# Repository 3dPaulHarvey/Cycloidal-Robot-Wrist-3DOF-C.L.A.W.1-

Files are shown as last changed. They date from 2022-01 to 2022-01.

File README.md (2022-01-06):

# Cycloidal-Robot-Wrist-3DOF-C.L.A.W.1-
Robot wrist with Cycloidal Gearboxes

Hello, this is one half of a Robot Arm. It is a 3 Degree of Freedom ROBOT WRIST. It is composed of 3 on-axis CYCLOIDAL gearboxes, with gt timing belts and pulleys driving them. This is a continuous motion wrist in all 3 axis.

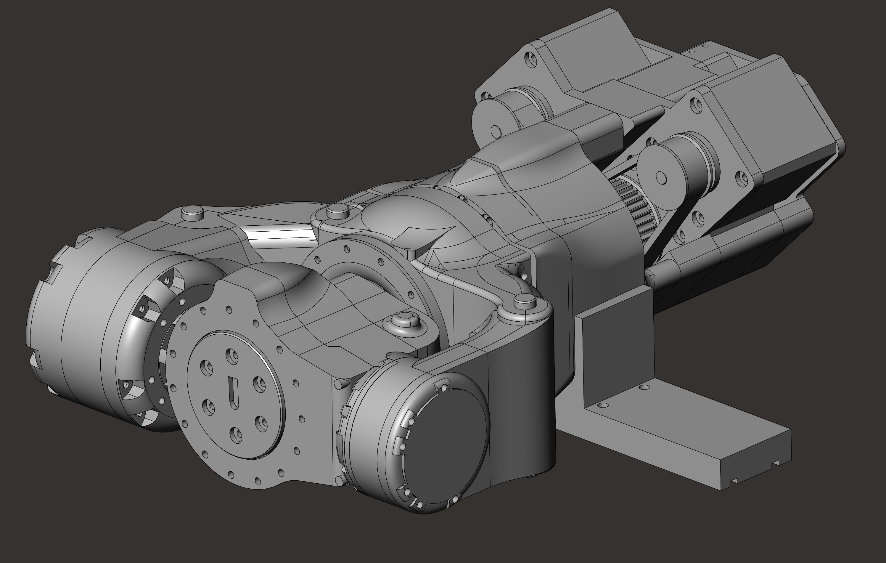
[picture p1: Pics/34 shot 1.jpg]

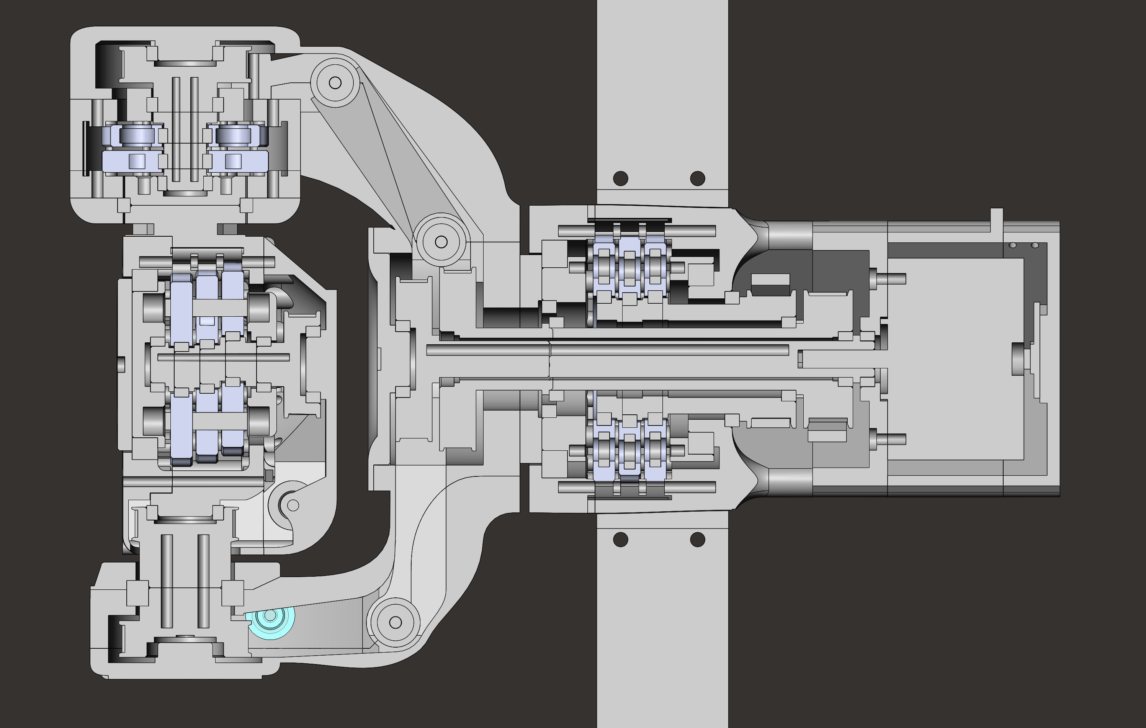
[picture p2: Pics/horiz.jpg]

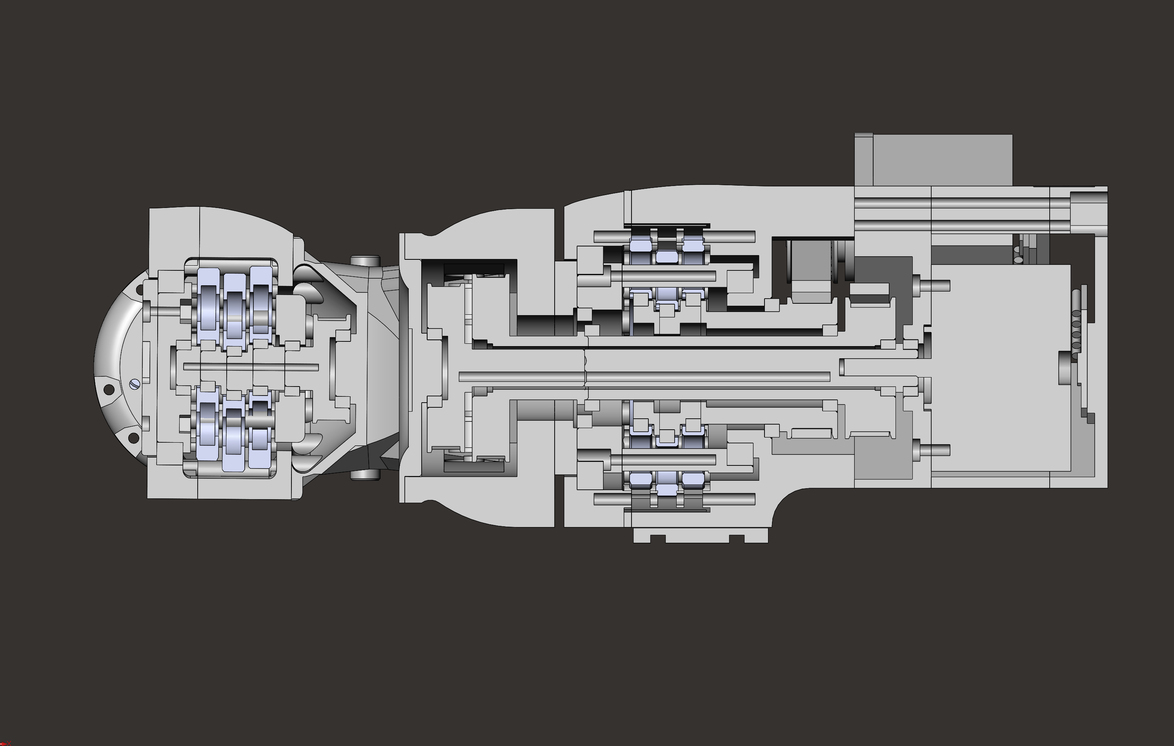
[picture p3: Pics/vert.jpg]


printed on prusa mk3 with overture petg
bom
lots of 3x5x5 sleeve bearings, 3mm bars, 4-40 screws, and other bearings

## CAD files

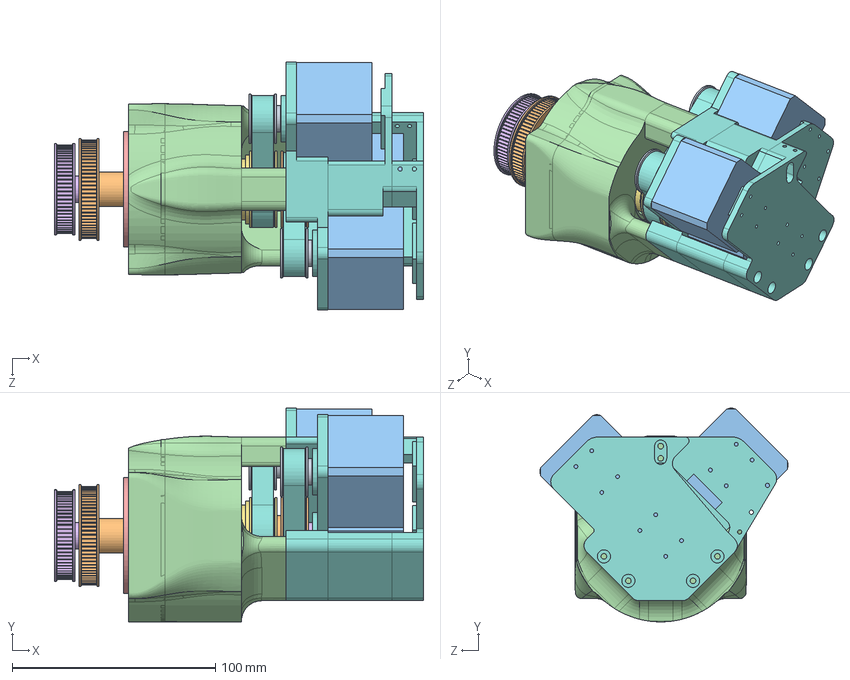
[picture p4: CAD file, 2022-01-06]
SolidWorks/ASSEM-F- 3DOF3 WRIST J4.SLDASM
181.6 x 105.2 x 122.3 mm
3D3- LEFT DRIVE PULLEY x 2
3D3- OUTER SHAFT
STEPPER 42 MM AZN2 x 3
3D3- J4- OUTER HOUSING
3D3- J4- OUTPUT CARRIAGE
3D3- INNER SHAFT
3D3- J4 ECCENTRIC SHAFT
3D3- MOTOR ATTACH2
Cycloidal Lobes 19-1, 70, 5, 1.5- B x 3
3D3-F-J4- 3MM PIN 1 x 20
BEARING- 3x5x5 x 20
3D3-F-J4- DUMMY PINS
3D3-F-J4- OUTPUT ROD
BEARING- 6x10x3 x 3

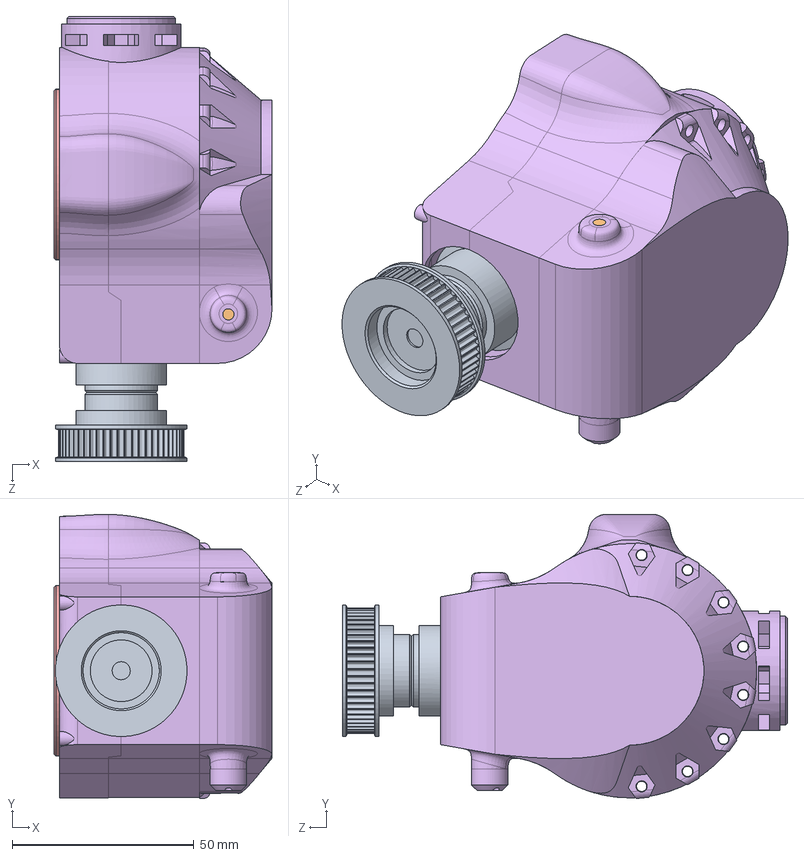
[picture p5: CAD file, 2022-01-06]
SolidWorks/ASSEM-F-J6- 3DOF3 WRIST.SLDASM
60.0 x 78.2 x 122.5 mm
3D3- J6-3- SIDE PULLEY
3D3- J6-3- 3MM BAR
3D3- J6-3- CORNER PULLEY x 2
3D3- J6-3- ECCENTRIC SHAFT
3D3- J6-3- INNER CARRIAGE
3D3- J6-3- OUTER HOUSING
3D3-F-J6- Cycloidal A 56 5 1.5 14-1 x 3
BEARING- 7x13x4 x 3
3D3- J6-3- 3MM PIN x 15
BEARING- 3x5x5 x 15
3D3-F-J6- DUMMY PINS

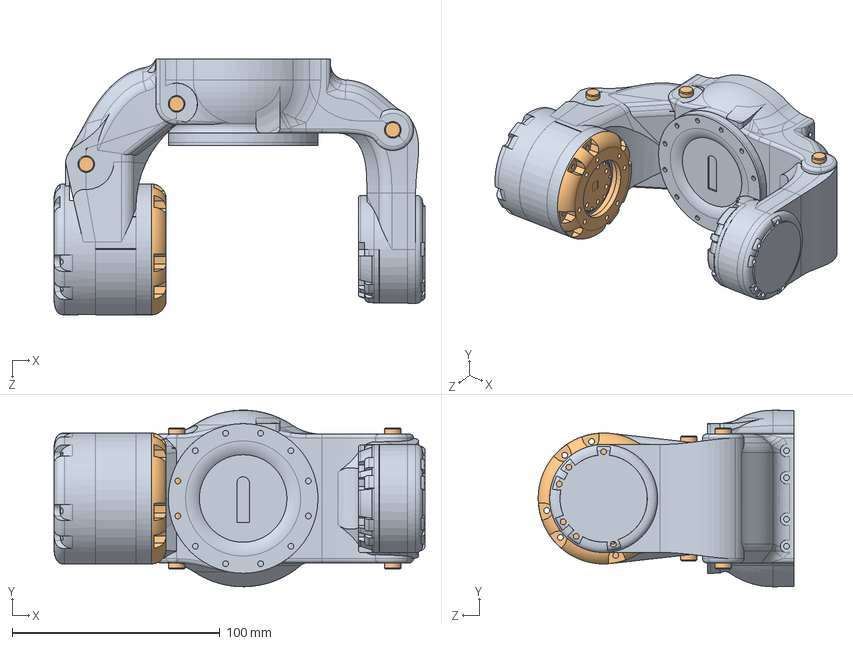
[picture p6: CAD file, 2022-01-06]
SolidWorks/ASSEM-F-J5- 3DOF3 WRIST.SLDASM
178.5 x 85.0 x 123.0 mm
3D3- J5-2- OUTER HOUSING
3D3- J5-2- MID WRIST FRAME
3D3- J6-3- CORNER PULLEY x 6
3D3-F-J5- 3MM CORNER BAR A
3D3-F-J5- 3MM CORNER BAR C
3D3-F-J5- 3MM CORNER BAR B
3D3-J5-2- CYCLOIDAL 11-1rat 48dia 5dia 1.5ecc A x 2
3D3- J5-2- ECCENTRIC SHAFT
3D3- J5-2- INNER CARRIAGE
BEARING- 5x10x4 x 2
3D3-F-J5- 3MM PINS x 12
BEARING- 3x5x5 x 12

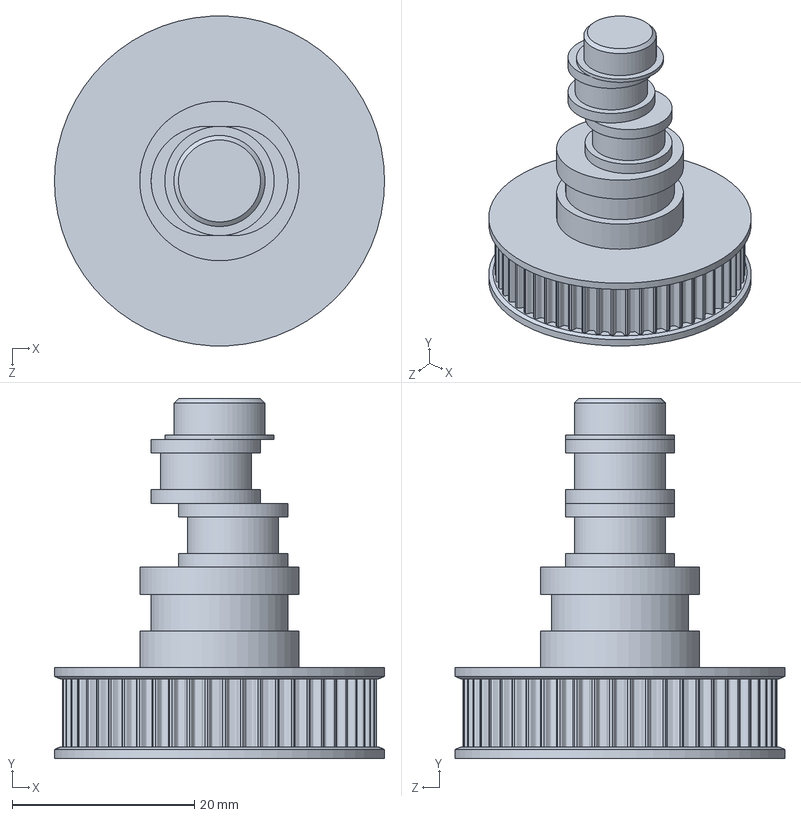
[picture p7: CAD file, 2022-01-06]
SolidWorks/3D3- J5-2- ECCENTRIC SHAFT.SLDPRT
36.2 x 39.5 x 36.2 mm

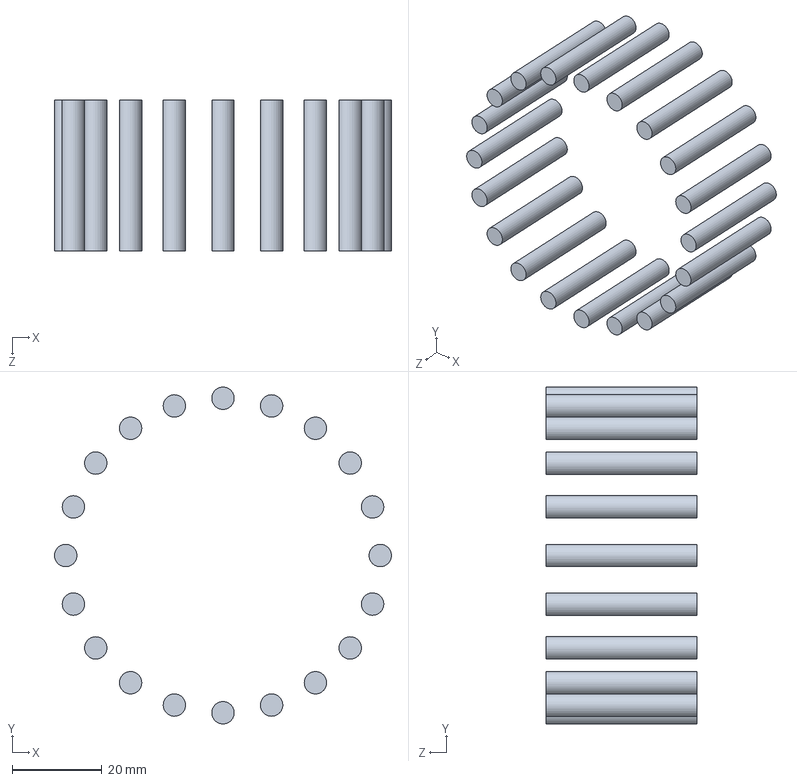
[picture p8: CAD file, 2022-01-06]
SolidWorks/3D3-F-J4- DUMMY PINS.SLDPRT
75.0 x 75.0 x 33.5 mm

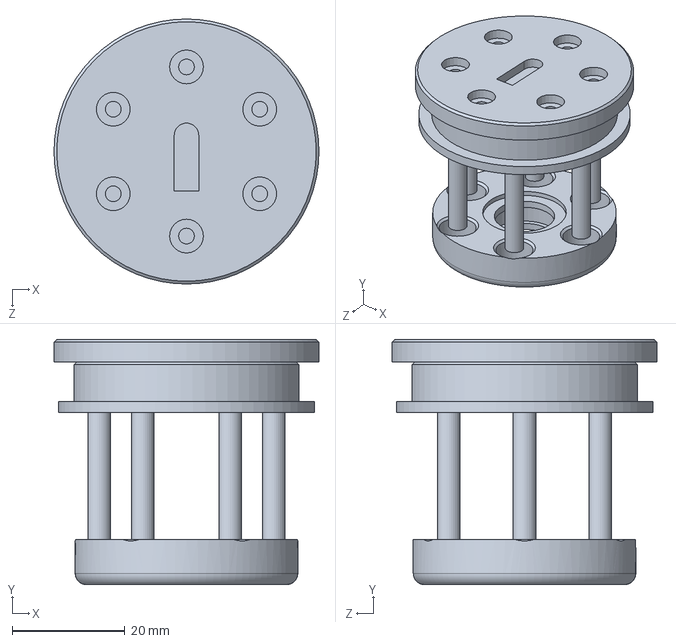
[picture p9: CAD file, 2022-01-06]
SolidWorks/3D3- J6-3- INNER CARRIAGE.SLDPRT
47.0 x 43.5 x 47.0 mm

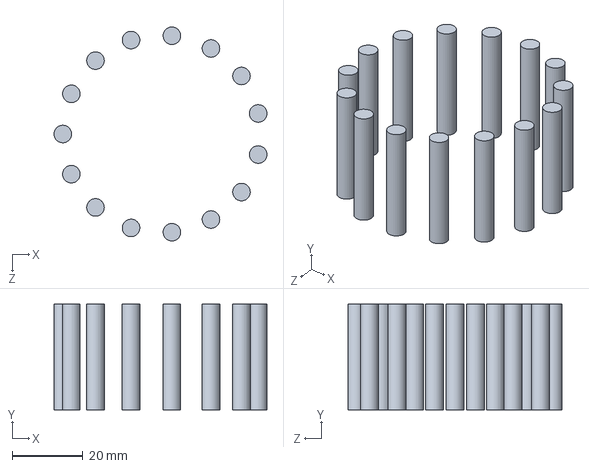
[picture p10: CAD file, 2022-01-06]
SolidWorks/3D3-F-J6- DUMMY PINS.SLDPRT
60.4 x 30.0 x 60.7 mm

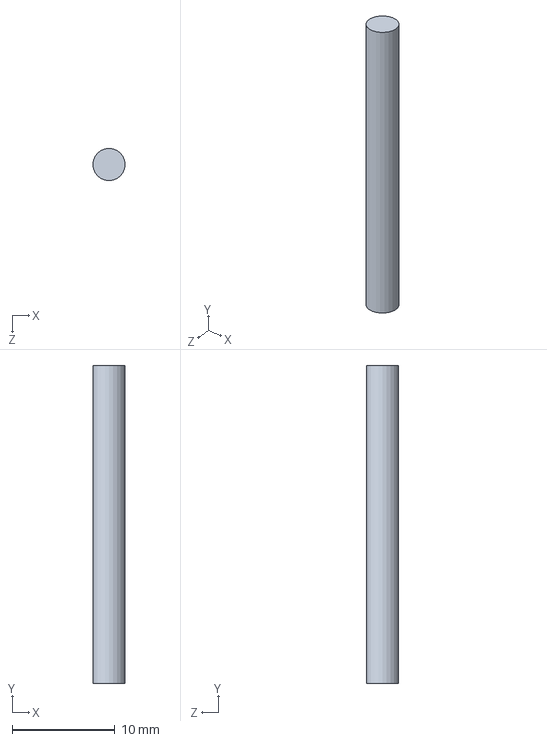
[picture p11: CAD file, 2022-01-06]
SolidWorks/3D3-F-J4- OUTPUT ROD.SLDPRT
3.15 x 31.0 x 3.15 mm

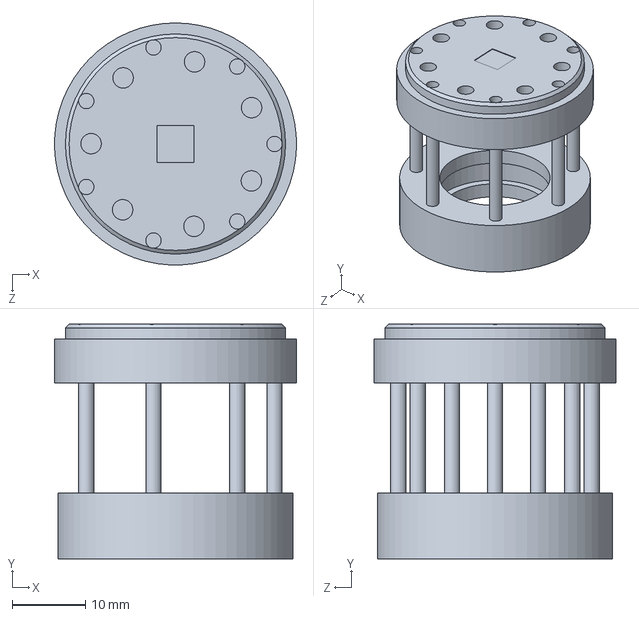
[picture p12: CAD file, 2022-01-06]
SolidWorks/3D3- J5-2- INNER CARRIAGE.SLDPRT
33.0 x 32.0 x 33.0 mm

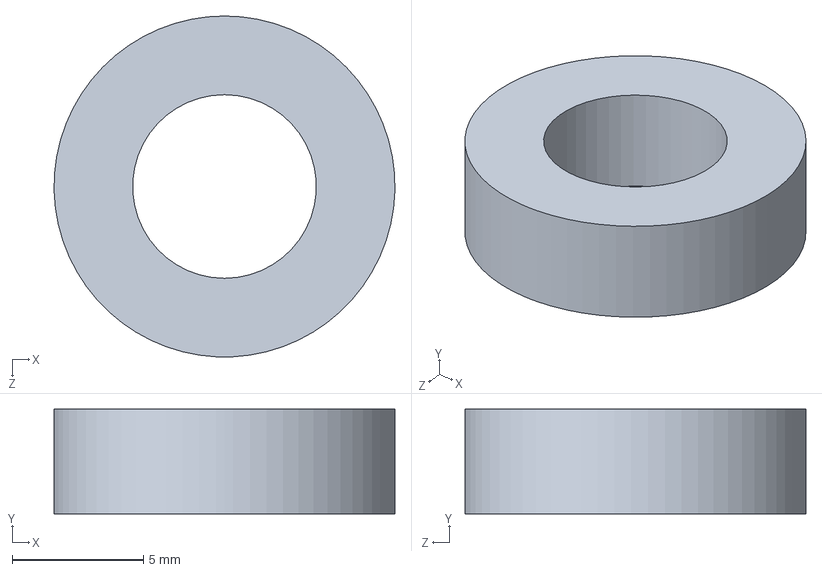
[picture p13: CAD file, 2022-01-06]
SolidWorks/BEARING- 7x13x4.SLDPRT
13.0 x 4.00 x 13.0 mm

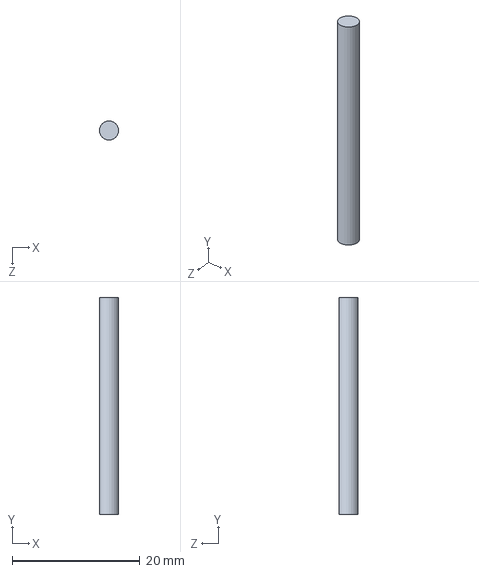
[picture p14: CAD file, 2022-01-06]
SolidWorks/3D3-F-J5- 3MM CORNER BAR A.SLDPRT
3.00 x 34.0 x 3.00 mm

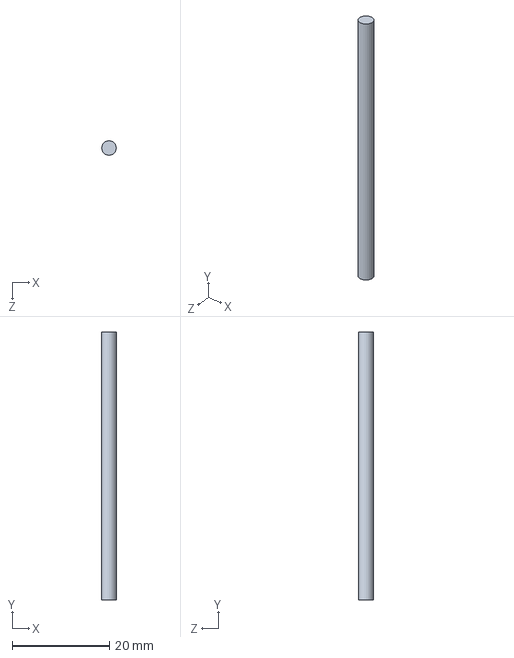
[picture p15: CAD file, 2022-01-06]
SolidWorks/3D3-F-J5- 3MM CORNER BAR C.SLDPRT
3.00 x 55.0 x 3.00 mm

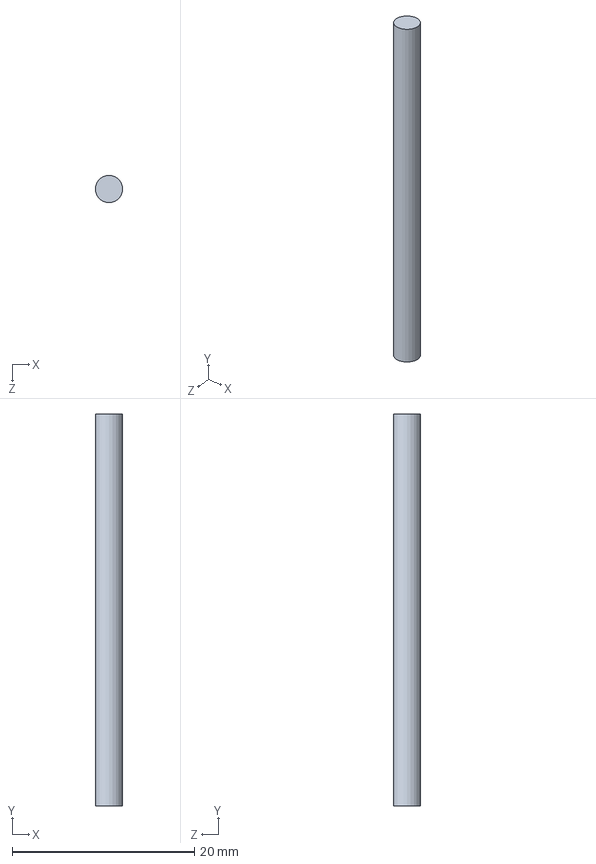
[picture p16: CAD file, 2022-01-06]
SolidWorks/3D3-F-J4- 3MM PIN 1.SLDPRT
3.00 x 43.0 x 3.00 mm

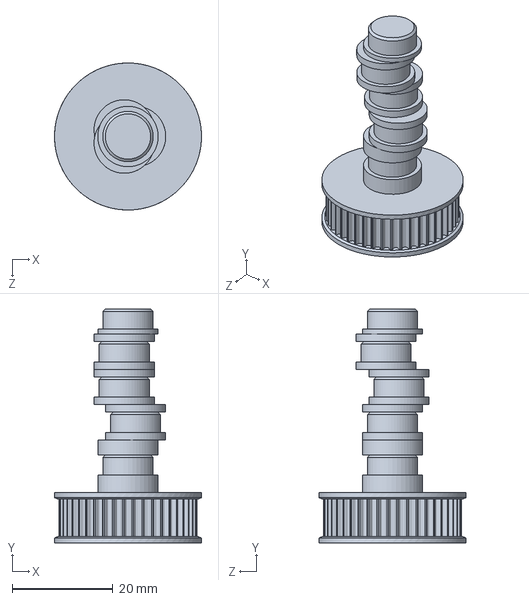
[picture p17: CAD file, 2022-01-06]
SolidWorks/3D3- J6-3- ECCENTRIC SHAFT.SLDPRT
29.2 x 46.5 x 29.2 mm

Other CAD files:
SolidWorks/3D3-F-J6- Cycloidal A 56 5 1.5 14-1.SLDPRT
SolidWorks/3D3- J6-3- 3MM PIN.SLDPRT
SolidWorks/BEARING- 5x10x4.SLDPRT
SolidWorks/3D3- J4 ECCENTRIC SHAFT.SLDPRT
SolidWorks/3D3- J4- OUTER HOUSING.SLDPRT
SolidWorks/3D3- J4- OUTPUT CARRIAGE.SLDPRT
SolidWorks/3D3- J5-2- MID WRIST FRAME.SLDPRT
SolidWorks/3D3- J6-3- 3MM BAR.SLDPRT
SolidWorks/3D3- J6-3- CORNER PULLEY.SLDPRT
SolidWorks/3D3- J6-3- SIDE PULLEY.SLDPRT
SolidWorks/3D3- LEFT DRIVE PULLEY.SLDPRT
SolidWorks/3D3- MOTOR ATTACH2.SLDPRT
SolidWorks/3D3- OUTER SHAFT.SLDPRT
SolidWorks/3D3-F-J5- 3MM CORNER BAR B.SLDPRT
SolidWorks/3D3-F-J5- 3MM PINS.SLDPRT
SolidWorks/3D3-F-J5- DUMMY PINS.SLDPRT
SolidWorks/3D3-J5-2- CYCLOIDAL 11-1rat 48dia 5dia 1.5ecc A.SLDPRT
SolidWorks/44.SLDPRT
SolidWorks/BEARING- 3x5x5.SLDPRT
SolidWorks/BEARING- 6x10x3.SLDPRT
SolidWorks/Cycloidal Lobes 19-1, 70, 5, 1.5- B.SLDPRT
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

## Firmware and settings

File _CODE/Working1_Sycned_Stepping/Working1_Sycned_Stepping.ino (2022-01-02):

//MACRO//
#define X_STEP_PIN 54
#define X_DIR_PIN  55
#define X_ENABLE_PIN 38
#define X_STEP_HIGH PORTF  |= B00000001;
#define X_STEP_LOW PORTF  &= ~B00000001;

#define Y_STEP_PIN 60
#define Y_DIR_PIN  61
#define Y_ENABLE_PIN 56
#define Y_STEP_HIGH   PORTF  |= B01000000;
#define Y_STEP_LOW    PORTF  &= ~B01000000;

#define A_STEP_PIN 26
#define A_DIR_PIN  28
#define A_ENABLE_PIN 24
#define A_STEP_HIGH PORTA  |= B00010000;
#define A_STEP_LOW PORTA  &= ~B00010000;

#define TIMER1_ON TIMSK1 |=(1<<OCIE1A);
#define TIMER1_OFF TIMSK1 &=~(1<<OCIE1A);


//STRUCT INFO//
struct joint {
  unsigned int startSpeed;
  volatile unsigned long maxSpeed;
  volatile unsigned long rampIndex;
  volatile unsigned long stepCount;
  volatile unsigned long totalSteps;
  volatile unsigned long accelStepCount;
  volatile float dMicros;
  volatile unsigned long dTrunc;
  volatile bool moveDone;

  volatile float timeScalar;
  unsigned long totalMoveDuration;
  unsigned long accelStepCountEst;
  unsigned long accelDuration;

  void (*setDirection) (int);
  void (*step) ();

  long position;
  volatile int direction;
  unsigned long stepsPerRevolution;
};


//STRUCT FUNCTIONS//
void xStep () {
  X_STEP_HIGH
  X_STEP_LOW
}
void xDirection (int dir) {
  digitalWrite (X_DIR_PIN, dir > 0 ? HIGH : LOW);
}
void yStep () {
  Y_STEP_HIGH
  Y_STEP_LOW
}
void yDirection (int dir) {
  digitalWrite (Y_DIR_PIN, dir > 0 ? HIGH : LOW);
}
void aStep () {
  A_STEP_HIGH
  A_STEP_LOW
}
void aDirection (int dir) {
  digitalWrite (A_DIR_PIN, dir > 0 ? HIGH : LOW);
}


//GLOBALS//
#define NUM_JOINTS 3
joint jointArray[NUM_JOINTS];
volatile byte jointRemain = 0;
volatile byte nextJoint = 0;
volatile float accelScalar = 0;
int resetButtonPin = 47;

//SETUP//
void setup() {
  Serial.begin(115200);
  pinMode (X_STEP_PIN, OUTPUT);
  pinMode (X_DIR_PIN, OUTPUT);
  pinMode (X_ENABLE_PIN, OUTPUT);
  digitalWrite (X_ENABLE_PIN, LOW);

  pinMode (Y_STEP_PIN, OUTPUT);
  pinMode (Y_DIR_PIN, OUTPUT);
  pinMode (Y_ENABLE_PIN, OUTPUT);
  digitalWrite (Y_ENABLE_PIN, LOW);

  pinMode (A_STEP_PIN, OUTPUT);
  pinMode (A_DIR_PIN, OUTPUT);
  pinMode (A_ENABLE_PIN, OUTPUT);
  digitalWrite (A_ENABLE_PIN, LOW);

  noInterrupts();
  TCCR1A = 0;
  TCCR1B = 0;
  TCNT1 = 0;
  OCR1A = 1000;
  TCCR1B |= (1 << WGM12);
  TCCR1B |= (0 << CS12) | (1 << CS11) | (1 << CS10);
  interrupts();

  jointArray[0].startSpeed = 1700;
  jointArray[0].maxSpeed = 85; //215
  jointArray[0].setDirection = xDirection;
  jointArray[0].step = xStep;

  jointArray[1].startSpeed = 2500;
  jointArray[1].maxSpeed = 255;
  jointArray[1].setDirection = yDirection;
  jointArray[1].step = yStep;

  jointArray[2].startSpeed = 1300;
  jointArray[2].maxSpeed = 80;
  jointArray[2].setDirection = aDirection;
  jointArray[2].step = aStep;

  //gear ratio setup
  double J4_gear_ratio = (37.0 / 23.0);
  long J4_one_rev_num_steps = ( 200 * 4 * J4_gear_ratio * 19);
  jointArray[2].stepsPerRevolution = J4_one_rev_num_steps;

  float J5_gear_ratio = (37.0 / 23.0); //1.6086
  float J5_gear_ratio_2 = (55.0 / 77.0); //0.7142
  long J5_one_rev_num_steps = ( 200 * 4 * J5_gear_ratio * J5_gear_ratio_2 * 11); //10109.98
  J5_one_rev_num_steps = 10800.0;

  float yGearRatio = (55.0 / 69.0); //0.7971
  long yOneRevolution = (200 * 4 * yGearRatio * 14); /// 8927
  yOneRevolution = 7175;
  jointArray[0].stepsPerRevolution = J5_one_rev_num_steps;
  jointArray[1].stepsPerRevolution = yOneRevolution;

}


//ISR//
ISR(TIMER1_COMPA_vect) {
  unsigned int previousTimeSlice = OCR1A;
  OCR1A = 65500;

  for (int i = 0; i < NUM_JOINTS; i++) {
    if ( ! ((1 << i) & jointRemain) )
      continue;
    if ( ! ((1 << i) & nextJoint) ) {
      jointArray[i].dTrunc -= previousTimeSlice;
      continue;
    }

    joint &ji = jointArray[i];
    if (ji.stepCount < ji.totalSteps) {
      ji.step();
      ji.stepCount++;
      ji.position += ji.direction;
      if (ji.stepCount >= ji.totalSteps) {
        ji.moveDone = true;
        jointRemain &= ~(1 << i);
      }
      if (ji.accelStepCount == 0) {
        ji.rampIndex++;
        ji.dMicros = ji.dMicros - (2 * ji.dMicros) / (4 * ji.rampIndex + 1 ); ///flash
        if ( ji.dMicros <= ji.maxSpeed) {
          ji.dMicros = ji.maxSpeed;
          ji.accelStepCount = ji.stepCount;
        }
        if ( ji.stepCount >= ji.totalSteps / 2 ) {
          ji.accelStepCount = ji.stepCount;
        }
      } else if (ji.stepCount >= ji.totalSteps - ji.accelStepCount) {
        //ji.dMicros = ji.dMicros + (2 * ji.dMicros) / (4 * ji.rampIndex + 1 - 2);//flash
        ji.dMicros = ( ji.dMicros * (4 * ji.rampIndex + 1) ) / (4 * ji.rampIndex + 1 - 2  );
        ji.rampIndex--;
      }
      ji.dTrunc = ji.dMicros * ji.timeScalar;
    }
  }
  calcNextInterval();
  TCNT1  = 0;
}


//NORMALIZE ACCELERATIONS
void normalizeAccelerations() {
  unsigned long largestMoveDuration = 0 ;

  for (int i = 0; i < NUM_JOINTS; i++) {
    if ( (jointArray[i].totalMoveDuration > largestMoveDuration) && ((1 << i) & jointRemain) ) {
      largestMoveDuration = jointArray[i].totalMoveDuration;
    }
  }
  for (int i = 0; i < NUM_JOINTS; i++) {
    if ( ((1 << i) &  jointRemain) ) {
      jointArray[i].timeScalar = float(largestMoveDuration) / float(jointArray[i].totalMoveDuration);
    }
  }
}


//GET DURATION OF ACCELERATION
float getDurationOfAcceleration (unsigned long accelStepCountEst, unsigned long startSpeed) {
  float accelDuration = 0;
  float timeSlice = startSpeed;

  for (unsigned int i = 1; i < accelStepCountEst; i++) {
    timeSlice = timeSlice - (2 * timeSlice) / (4 * i + 1 );
    accelDuration += timeSlice;
  }
  return accelDuration;
}


//ESTIMATE ACCEL STEP COUNT
void estimateAccelStepCount (joint& ji) {
  float timeSlice = ji.startSpeed;

  for (int i = 1; i < ji.totalSteps / 2; i++) {
    timeSlice = timeSlice - (2 * timeSlice) / (4 * i + 1  );
    //Serial.println(timeSlice);
    ji.accelStepCountEst++;
    if (timeSlice < ji.maxSpeed) {
      return;
    }
  }
}


//PREPARE MOVE//
void prepareMove(int whichJoint, long desiredPosition) {
  joint &ji = jointArray[whichJoint]; // type
  long numSteps = desiredPosition - ji.position;
  ji.stepCount = 0;
  ji.accelStepCount = 0;
  ji.rampIndex = 0;
  ji.dMicros = ji.startSpeed;
  ji.dTrunc = ji.dMicros;
  ji.totalSteps = abs (numSteps);
  ji.moveDone = false;
  if (ji.totalSteps != 0) {
    jointRemain |= (1 << whichJoint);
  }
  ji.timeScalar = 1.0;
  ji.accelDuration = 0;
  ji.totalMoveDuration = 0;
  ji.accelStepCountEst = 0;

  ji.setDirection  (numSteps > 0 ? 1 : -1);
  ji.direction = (numSteps > 0 ? 1 : -1);

  estimateAccelStepCount (ji);

  float tempStartSpeed = ji.startSpeed;

  //will max speed before halfway
  if ( ji.accelStepCountEst >= ji.totalSteps / 2) {
    ji.accelStepCountEst = ji.totalSteps / 2;
    ji.accelDuration = getDurationOfAcceleration (ji.accelStepCountEst, tempStartSpeed);
    ji.totalMoveDuration = ji.accelDuration * 2;
  } else { //some time spent at max speed
    ji.accelDuration = getDurationOfAcceleration (ji.accelStepCountEst, tempStartSpeed);
    ji.totalMoveDuration = (ji.accelDuration * 2) + ( ji.maxSpeed * (ji.totalSteps - (2 * ji.accelStepCountEst)) );
  }
}


//CALCULATE NEXTINTERVAL//
void calcNextInterval () {
  volatile unsigned int previousTimeSlice = 9999999;

  for (int i = 0; i < NUM_JOINTS; i++) {
    if ( (jointArray[i].dTrunc < previousTimeSlice) && ((1 << i) & jointRemain) ) {
      previousTimeSlice = jointArray[i].dTrunc;
    }
  }
  nextJoint = 0;
  for (int i = 0; i < NUM_JOINTS; i++) {
    if ( (jointArray[i].dTrunc == previousTimeSlice) && ((1 << i) & jointRemain) ) {
      nextJoint |= (1 << i);
    }
  }
  if (nextJoint == 0) {
    OCR1A = 65500;
    TIMER1_OFF
  }
  OCR1A = previousTimeSlice;
}


//RUN AND WAIT//
void runAndWait() {
  normalizeAccelerations();
  calcNextInterval();
  TIMER1_ON
  while (jointRemain != 0);
  nextJoint = 0;
  jointRemain = 0;
}


//RESET HOME POSITION//
void resetHomePosition () {
  for (int i = 0; i < NUM_JOINTS; i++) {
    jointArray[i].position = 0;
  }
  delay(500);
}

//DoubleSpeed
void doubleSpeed () {
  TCCR1B &= ~(1 << CS10);
  jointArray[0].maxSpeed *= 2;
  jointArray[1].maxSpeed *= 2;
  jointArray[2].maxSpeed *= 2;
  jointArray[0].startSpeed *= 2;
  jointArray[1].startSpeed *= 2;
  jointArray[2].startSpeed *= 2;

}

//Serial Input
void serialInput() {


  //SERIAL INPUT//
  unsigned long xInput, yInput, aInput;
  char rawData[100] = "";   //start with clear array
  Serial.println("Input position seperated by spaces");

  while (1) {
    //button for reset
    if ( digitalRead(resetButtonPin) == HIGH ) {
      resetHomePosition();
    }
    //reads in data from serial command line
    if (Serial.available() > 0) { //new Data in
      size_t byteCount = Serial.readBytesUntil('\n', rawData, sizeof(rawData) - 1);  // set serial monitor to "newline"
      rawData[byteCount] = NULL;  //put the end char on the string
      Serial.print("Raw Data = ");
      Serial.println(rawData);

      ////////////parsing our data
      const char delimiter[] = " ";
      char parsedStrings [5][20]; //array of strings, maxtrix of char
      char *token = strtok(rawData, delimiter);
      // check if NULL
      strncpy(parsedStrings[0], token, sizeof(parsedStrings[0]));
      for (int i = 1; i < 5; i++)
      {
        token = strtok(NULL, delimiter);//goes to the next
        strncpy(parsedStrings[i], token, sizeof(parsedStrings[i]));
      }
      for (int i = 0; i < 5; i++)
        Serial.println( parsedStrings[i]);

      ////////////////converting our data
      xInput = atol(parsedStrings[0]);
      Serial.println(xInput);
      yInput = atol(parsedStrings[1]);
      Serial.println(yInput);
      aInput = atol(parsedStrings[2]);
      Serial.println(aInput);
      if ( jointArray[0].position - xInput != 0 ) {
        prepareMove(0, xInput);
      }
      if ( jointArray[1].position - yInput != 0 ) {
        prepareMove(1, yInput);
      }
      if ( jointArray[2].position - aInput != 0 ) {
        prepareMove(2, aInput);
      }
      runAndWait();
    }
  }//end while

}

///////////////////////////////////////LOOP//
void loop() {
  delay(1000);

  resetHomePosition();
  doubleSpeed();
  showRoutine1();
  serialInput();

  delay(500);

  while ( true );

}

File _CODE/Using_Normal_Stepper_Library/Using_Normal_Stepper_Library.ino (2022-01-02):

int num_buttons_pressed = 0;

//j4
#define X_DIR_PIN          55
#define X_STEP_PIN         54
#define X_ENABLE_PIN       38
float J5_gear_ratio = (37.0 / 23.0);
float J5_gear_ratio_2 = (55.0 / 77.0);
long J5_one_rev_num_steps = ( 200 * 4 * J5_gear_ratio * J5_gear_ratio_2 * 11);
float J5_J6_axis_gear_ratio = (55.0 / 69.0);
int J4_CW_button_pin = 16;
int J4_CCW_button_pin = 17;



//j5
#define Y_DIR_PIN          61
#define Y_STEP_PIN         60
#define Y_ENABLE_PIN       56
double J4_gear_ratio = (37.0 / 23.0);
long J4_one_rev_num_steps = ( 200 * 4 * J4_gear_ratio * 19);
int J5_CW_button_pin = 25;
int J5_CCW_button_pin = 23;


//j6
#define A_DIR_PIN          28
#define A_STEP_PIN         26
#define A_ENABLE_PIN       24
int J6_CW_button_pin = 47;
int J6_CCW_button_pin = 32;




void setup() {
  Serial.begin(115200);
  // Declare pins as output:
  pinMode(X_STEP_PIN, OUTPUT);
  pinMode(X_DIR_PIN, OUTPUT);
  pinMode(X_ENABLE_PIN, OUTPUT);
  digitalWrite(X_ENABLE_PIN, LOW);
  digitalWrite(X_DIR_PIN, HIGH);

  pinMode(Y_STEP_PIN, OUTPUT);
  pinMode(Y_DIR_PIN, OUTPUT);
  pinMode(Y_ENABLE_PIN, OUTPUT);
  digitalWrite(Y_ENABLE_PIN, LOW);

  pinMode(A_STEP_PIN, OUTPUT);
  pinMode(A_DIR_PIN, OUTPUT);
  pinMode(A_ENABLE_PIN, OUTPUT);
  digitalWrite(A_ENABLE_PIN, LOW);

}

void loop() {
  int J4_CW_button = digitalRead(J4_CW_button_pin);
  int J4_CCW_button = digitalRead(J4_CCW_button_pin);
  int J5_CW_button = digitalRead(J5_CW_button_pin);
  int J5_CCW_button = digitalRead(J5_CCW_button_pin);
  int J6_CW_button = digitalRead(J6_CW_button_pin);
  int J6_CCW_button = digitalRead(J6_CCW_button_pin);

  num_buttons_pressed = J4_CW_button + J5_CW_button;


  if (digitalRead(J4_CW_button_pin) == HIGH) {
    digitalWrite(X_DIR_PIN, LOW);
    digitalWrite(X_STEP_PIN, HIGH);
    delayMicroseconds(200);
    digitalWrite(X_STEP_PIN, LOW);
    delayMicroseconds(200);

  } else  if (digitalRead(J4_CCW_button_pin) == HIGH) {
    digitalWrite(X_DIR_PIN, HIGH);
    digitalWrite(X_STEP_PIN, HIGH);
    delayMicroseconds(200);
    digitalWrite(X_STEP_PIN, LOW);
    delayMicroseconds(200);

  }

  if (digitalRead(J5_CW_button_pin) == HIGH) {
    digitalWrite(Y_DIR_PIN, LOW);
    digitalWrite(Y_STEP_PIN, HIGH);
    delayMicroseconds(200);
    digitalWrite(Y_STEP_PIN, LOW);
    delayMicroseconds(200);

  }
  if (digitalRead(J5_CCW_button_pin) == HIGH) {
    digitalWrite(Y_DIR_PIN, HIGH);
    digitalWrite(Y_STEP_PIN, HIGH);
    delayMicroseconds(200);
    digitalWrite(Y_STEP_PIN, LOW);
    delayMicroseconds(200);

  }

  
  if (digitalRead(J6_CW_button_pin) == HIGH) {

    digitalWrite(A_DIR_PIN, LOW);
    digitalWrite(A_STEP_PIN, HIGH);
    delayMicroseconds(150);
    digitalWrite(A_STEP_PIN, LOW);
    delayMicroseconds(150);

  }
  if (digitalRead(J6_CCW_button_pin) == HIGH) {
 
    digitalWrite(A_DIR_PIN, HIGH);
    digitalWrite(A_STEP_PIN, HIGH);
    delayMicroseconds(150);
    digitalWrite(A_STEP_PIN, LOW);
    delayMicroseconds(150);

  }


  /*
    //////j4//////////
    digitalWrite(X_DIR_PIN, HIGH);

    delay(2000);

    // Spin the stepper motor 1 revolution slowly:
    for (int i = 0; i < J4_one_rev_num_steps; i++) {
      // These four lines result in 1 step:
      digitalWrite(X_STEP_PIN, HIGH);
      delayMicroseconds(100);
      digitalWrite(X_STEP_PIN, LOW);
      delayMicroseconds(100);
    }

    delay(1000);

    // Set the spinning direction counterclockwise:
    digitalWrite(X_DIR_PIN, LOW);

    // Spin the stepper motor 1 revolution quickly:
    for (int i = 0; i < J4_one_rev_num_steps; i++) {
      // These four lines result in 1 step:
      digitalWrite(X_STEP_PIN, HIGH);
      delayMicroseconds(100);
      digitalWrite(X_STEP_PIN, LOW);
      delayMicroseconds(100);
    }


    //////j5////////////
    digitalWrite(Y_DIR_PIN, HIGH);

    delay(2000);

    // Spin the stepper motor 1 revolution slowly:
    for (int i = 0; i < J5_one_rev_num_steps; i++) {
    // These four lines result in 1 step:
    digitalWrite(Y_STEP_PIN, HIGH);
    delayMicroseconds(100);
    digitalWrite(Y_STEP_PIN, LOW);
    delayMicroseconds(100);
    }

    delay(1000);

    // Set the spinning direction counterclockwise:
    digitalWrite(Y_DIR_PIN, LOW);

    // Spin the stepper motor 1 revolution quickly:
    for (int i = 0; i < J5_one_rev_num_steps; i++) {
    // These four lines result in 1 step:
    digitalWrite(Y_STEP_PIN, HIGH);
    delayMicroseconds(100);
    digitalWrite(Y_STEP_PIN, LOW);
    delayMicroseconds(100);
    }



    //////j6//////////
    digitalWrite(A_DIR_PIN, HIGH);

    delay(2000);

    // Spin the stepper motor 1 revolution slowly:
    for (int i = 0; i < J5_one_rev_num_steps; i++) {
    // These four lines result in 1 step:
    digitalWrite(A_STEP_PIN, HIGH);
    delayMicroseconds(100);
    digitalWrite(A_STEP_PIN, LOW);
    delayMicroseconds(100);
    }

    delay(1000);

    // Set the spinning direction counterclockwise:
    digitalWrite(A_DIR_PIN, LOW);

    // Spin the stepper motor 1 revolution quickly:
    for (int i = 0; i < J5_one_rev_num_steps; i++) {
    // These four lines result in 1 step:
    digitalWrite(A_STEP_PIN, HIGH);
    delayMicroseconds(100);
    digitalWrite(A_STEP_PIN, LOW);
    delayMicroseconds(100);
    }

  */

}
